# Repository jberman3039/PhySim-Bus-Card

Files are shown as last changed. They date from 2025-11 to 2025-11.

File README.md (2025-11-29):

# Physics-Simulating-Business-Card
 
The "Physics Simulating Business Card" is a electronic business card that runs on an STM32L412K8. The card contains an 8X8 LED matrix. The pixels in the matrix are individually addressable with a 74HC595 shift register controlling selecting rows and T2N7002 N-Channel MOSFETs controlling the columns. An MXC6655XA accelerometer is used to track orientation of the card which is used as input to a fluid simulation displayed on the LED matrix. This project is inspired by https://github.com/Nicholas-L-Johnson/flip-card.

Schematic
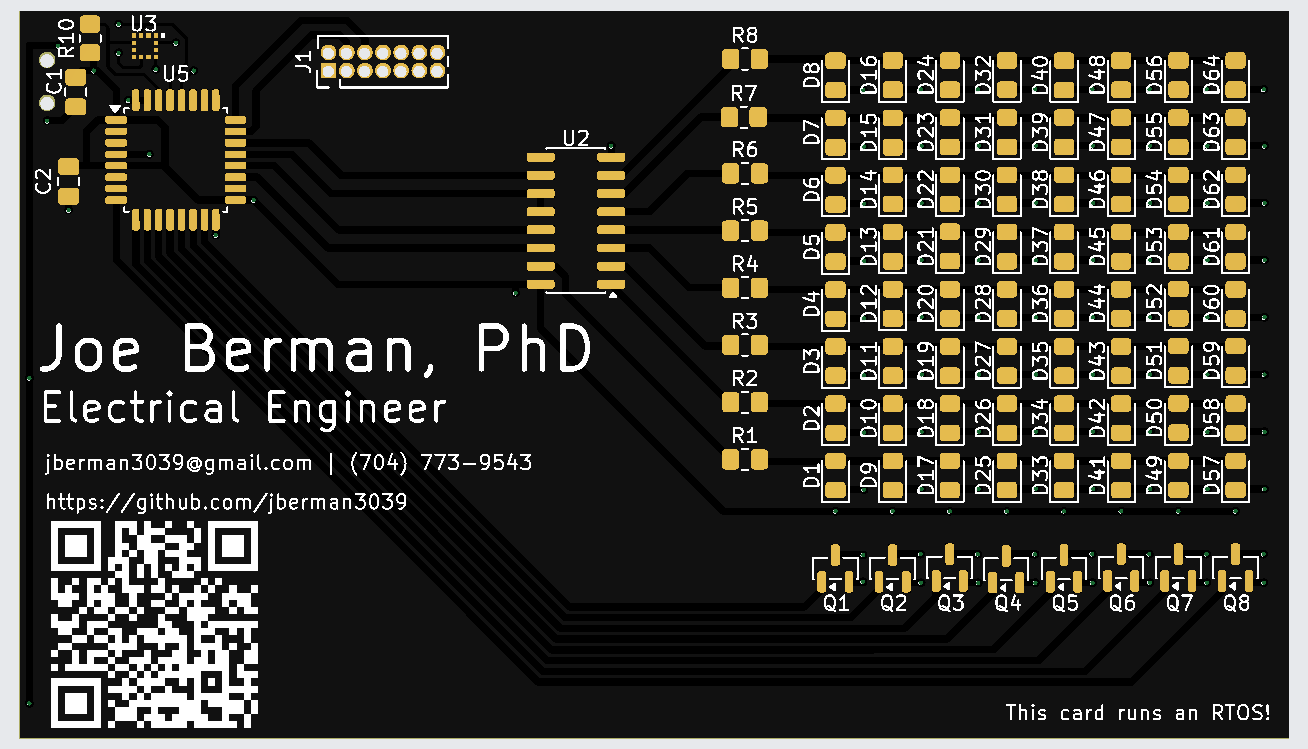
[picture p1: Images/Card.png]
PCB Design


# TODO

The firmware is currently in development. The STM32L412K8 will run CMSIS-RTOS for multi-threading tasks and will feature a custom driver for the MXC6655XA accelerometer.

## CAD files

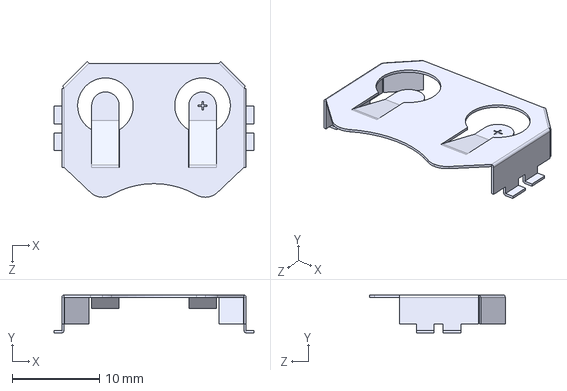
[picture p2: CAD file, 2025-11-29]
KiCad/BAT-HLD-001/BAT-HLD-001.step
22.9 x 4.32 x 15.5 mm

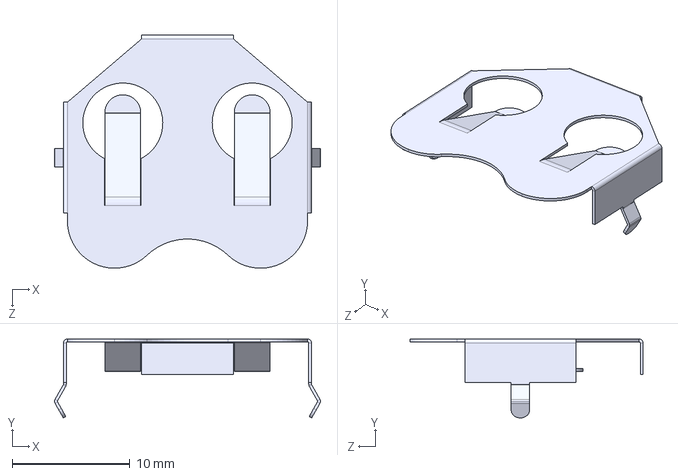
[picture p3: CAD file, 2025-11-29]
KiCad/BK_888_TR/BK-888.step
22.6 x 6.71 x 19.8 mm

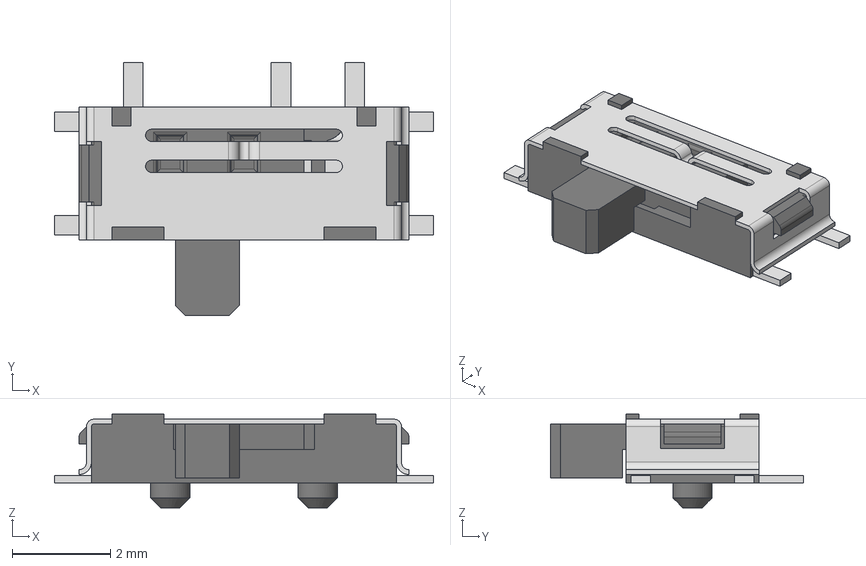
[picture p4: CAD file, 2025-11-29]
KiCad/450404015514/450404015514.step
7.70 x 5.13 x 1.90 mm
Frame
Pin 4
Frame 1
Pin 1
Pin 2
Pin 3
Slider 1
Slider
Cover

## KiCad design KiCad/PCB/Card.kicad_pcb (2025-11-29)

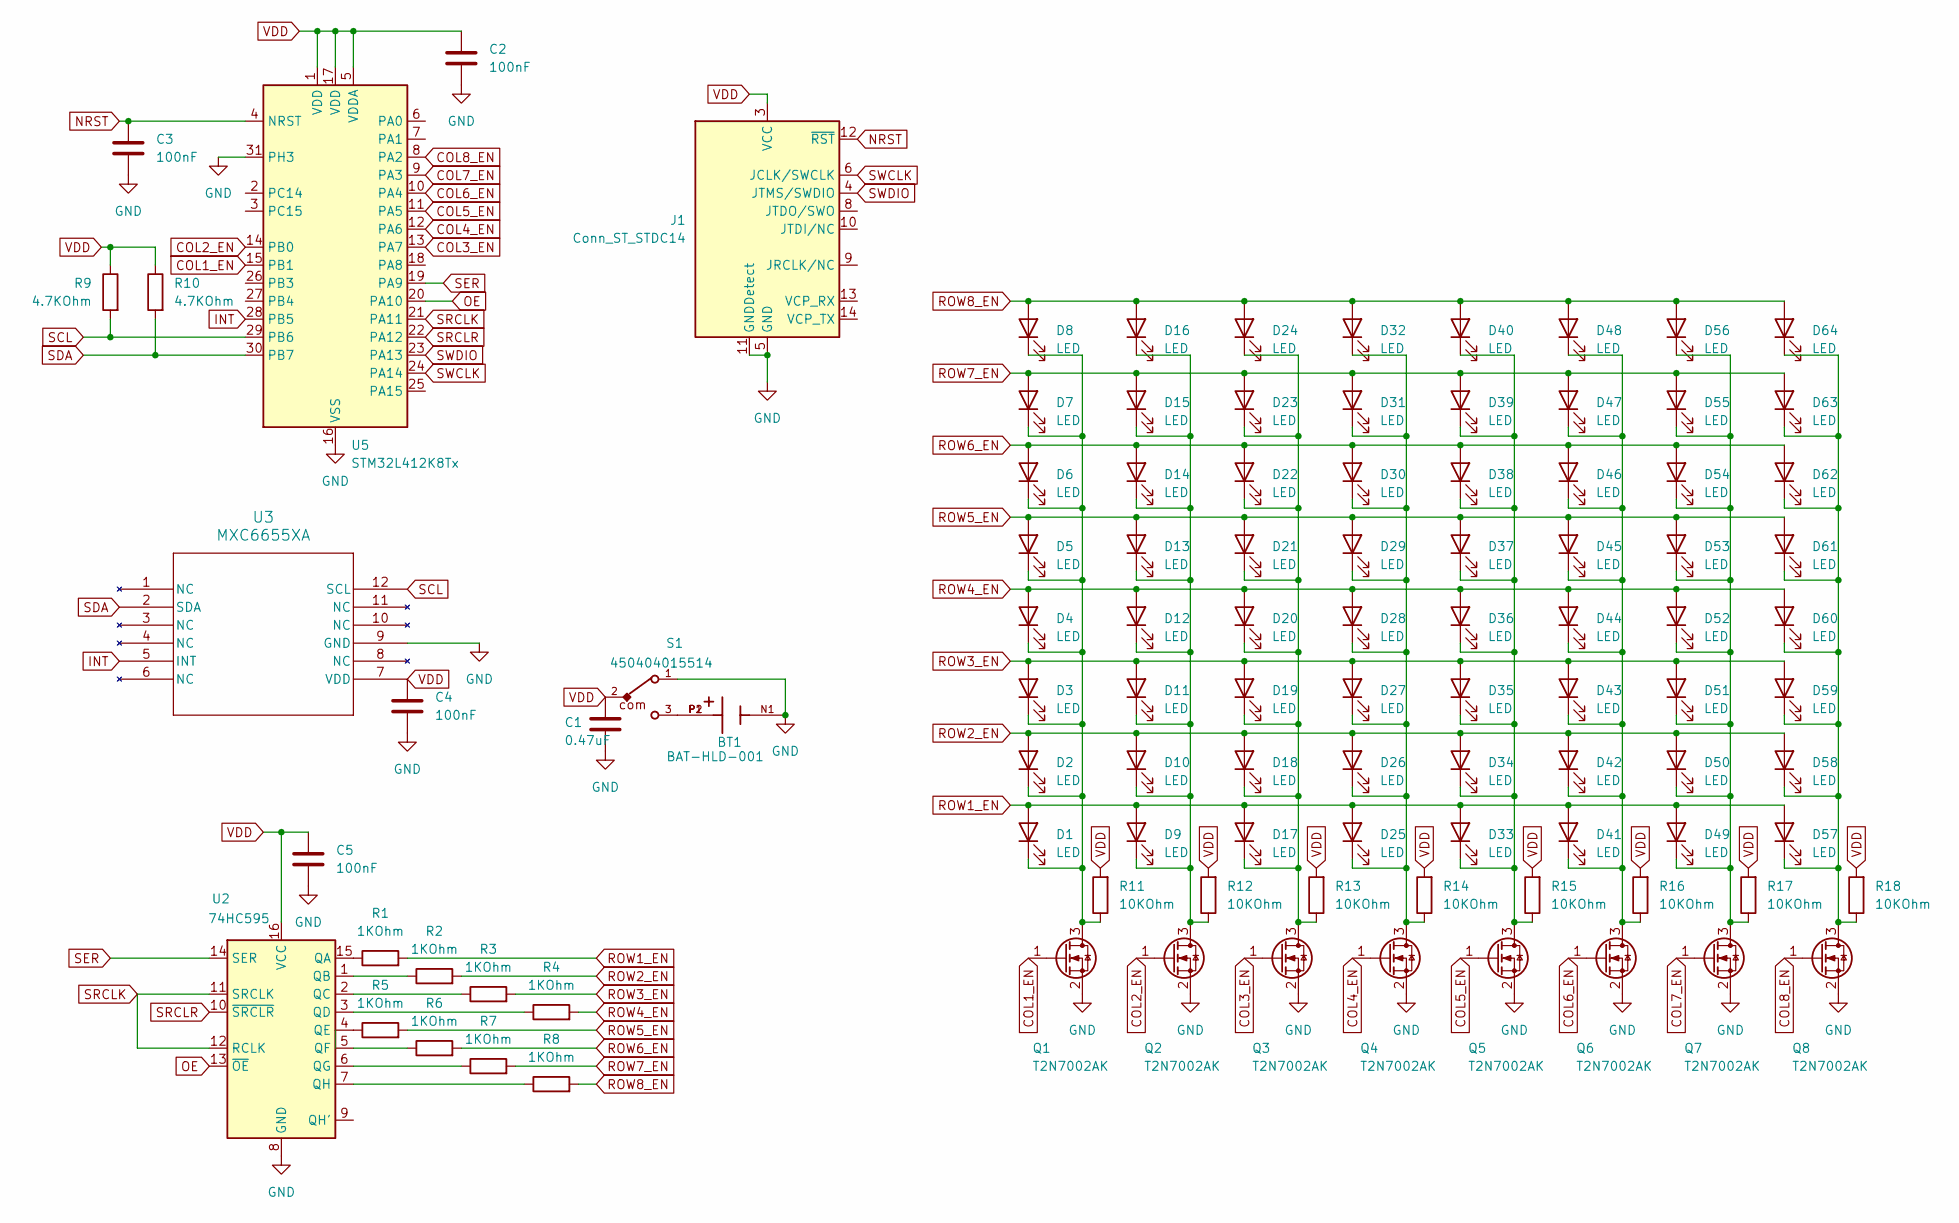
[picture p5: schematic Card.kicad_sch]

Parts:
BT1: BAT-HLD-001; BAT_BAT-HLD-001; PARTREV C
C1: 0.47uF; C_0805_2012Metric_Pad1.18x1.45mm_HandSolder
C2, C3, C4, C5: 100nF; C_0805_2012Metric_Pad1.18x1.45mm_HandSolder
D1, D2, D3, D4, D5, D6, D7, D8, D9, D10, D11, D12, D13, D14, D15, D16, D17, D18, D19, D20, D21, D22, D23, D24, D25, D26, D27, D28, D29, D30, D31, D32, D33, D34, D35, D36, D37, D38, D39, D40, D41, D42, D43, D44, D45, D46, D47, D48, D49, D50, D51, D52, D53, D54, D55, D56, D57, D58, D59, D60, D61, D62, D63, D64: LED; LED_0805_2012Metric_Pad1.15x1.40mm_HandSolder
J1: Conn_ST_STDC14; PinHeader_2x07_P1.27mm_Vertical
Q1, Q2, Q3, Q4, Q5, Q6, Q7, Q8: T2N7002AK; SOT-23
R1, R2, R3, R4, R5, R6, R7, R8: 1KOhm; R_0805_2012Metric_Pad1.20x1.40mm_HandSolder
R9, R10: 4.7KOhm; R_0805_2012Metric_Pad1.20x1.40mm_HandSolder
R11, R12, R13, R14, R15, R16, R17, R18: 10KOhm; R_0805_2012Metric_Pad1.20x1.40mm_HandSolder
S1: 450404015514
U2: 74HC595; SOIC-16_3.9x9.9mm_P1.27mm
U3: MXC6655XA; MXC6655XA_MEM
U5: STM32L412K8Tx; LQFP-32_7x7mm_P0.8mm

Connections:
COL1_EN: Q1.1 (G), U5.15 (PB1)
COL2_EN: Q2.1 (G), U5.14 (PB0)
COL3_EN: Q3.1 (G), U5.13 (PA7)
COL4_EN: Q4.1 (G), U5.12 (PA6)
COL5_EN: Q5.1 (G), U5.11 (PA5)
COL6_EN: Q6.1 (G), U5.10 (PA4)
COL7_EN: Q7.1 (G), U5.9 (PA3)
COL8_EN: Q8.1 (G), U5.8 (PA2)
GND: BT1.N1, C1.2, C2.2, C3.2, C4.2, C5.2, J1.5 (GND), J1.7 (GND), J1.11 (GNDDetect), Q1.2 (S), Q2.2 (S), Q3.2 (S), Q4.2 (S), Q5.2 (S), Q6.2 (S), Q7.2 (S), Q8.2 (S), S1.1, U2.8 (GND), U3.9 (GND), U5.16 (VSS), U5.31 (PH3), U5.32 (VSS)
INT: U3.5 (INT), U5.28 (PB5)
NRST: C3.1, J1.12 (~RST), U5.4 (NRST)
unnamed: BT1.P1, BT1.P2, S1.3
unnamed: D1.1 (K), D2.1 (K), D3.1 (K), D4.1 (K), D5.1 (K), D6.1 (K), D7.1 (K), D8.1 (K), Q1.3 (D), R11.1
unnamed: D9.1 (K), D10.1 (K), D11.1 (K), D12.1 (K), D13.1 (K), D14.1 (K), D15.1 (K), D16.1 (K), Q2.3 (D), R12.1
unnamed: D17.1 (K), D18.1 (K), D19.1 (K), D20.1 (K), D21.1 (K), D22.1 (K), D23.1 (K), D24.1 (K), Q3.3 (D), R13.1
unnamed: D25.1 (K), D26.1 (K), D27.1 (K), D28.1 (K), D29.1 (K), D30.1 (K), D31.1 (K), D32.1 (K), Q4.3 (D), R14.1
unnamed: D33.1 (K), D34.1 (K), D35.1 (K), D36.1 (K), D37.1 (K), D38.1 (K), D39.1 (K), D40.1 (K), Q5.3 (D), R15.1
unnamed: D41.1 (K), D42.1 (K), D43.1 (K), D44.1 (K), D45.1 (K), D46.1 (K), D47.1 (K), D48.1 (K), Q6.3 (D), R16.1
unnamed: D49.1 (K), D50.1 (K), D51.1 (K), D52.1 (K), D53.1 (K), D54.1 (K), D55.1 (K), D56.1 (K), Q7.3 (D), R17.1
unnamed: D57.1 (K), D58.1 (K), D59.1 (K), D60.1 (K), D61.1 (K), D62.1 (K), D63.1 (K), D64.1 (K), Q8.3 (D), R18.1
unnamed: R1.1, U2.15 (QA)
unnamed: R2.1, U2.1 (QB)
unnamed: R3.1, U2.2 (QC)
unnamed: R4.1, U2.3 (QD)
unnamed: R5.1, U2.4 (QE)
unnamed: R6.1, U2.5 (QF)
unnamed: R7.1, U2.6 (QG)
unnamed: R8.1, U2.7 (QH)
OE: U2.13 (~OE), U5.20 (PA10)
ROW1_EN: D1.2 (A), D9.2 (A), D17.2 (A), D25.2 (A), D33.2 (A), D41.2 (A), D49.2 (A), D57.2 (A), R1.2
ROW2_EN: D2.2 (A), D10.2 (A), D18.2 (A), D26.2 (A), D34.2 (A), D42.2 (A), D50.2 (A), D58.2 (A), R2.2
ROW3_EN: D3.2 (A), D11.2 (A), D19.2 (A), D27.2 (A), D35.2 (A), D43.2 (A), D51.2 (A), D59.2 (A), R3.2
ROW4_EN: D4.2 (A), D12.2 (A), D20.2 (A), D28.2 (A), D36.2 (A), D44.2 (A), D52.2 (A), D60.2 (A), R4.2
ROW5_EN: D5.2 (A), D13.2 (A), D21.2 (A), D29.2 (A), D37.2 (A), D45.2 (A), D53.2 (A), D61.2 (A), R5.2
ROW6_EN: D6.2 (A), D14.2 (A), D22.2 (A), D30.2 (A), D38.2 (A), D46.2 (A), D54.2 (A), D62.2 (A), R6.2
ROW7_EN: D7.2 (A), D15.2 (A), D23.2 (A), D31.2 (A), D39.2 (A), D47.2 (A), D55.2 (A), D63.2 (A), R7.2
ROW8_EN: D8.2 (A), D16.2 (A), D24.2 (A), D32.2 (A), D40.2 (A), D48.2 (A), D56.2 (A), D64.2 (A), R8.2
SCL: R9.2, U3.12 (SCL), U5.29 (PB6)
SDA: R10.2, U3.2 (SDA), U5.30 (PB7)
SER: U2.14 (SER), U5.19 (PA9)
SRCLK: U2.11 (SRCLK), U2.12 (RCLK), U5.21 (PA11)
SRCLR: U2.10 (~SRCLR), U5.22 (PA12)
SWCLK: J1.6 (JCLK/SWCLK), U5.24 (PA14)
SWDIO: J1.4 (JTMS/SWDIO), U5.23 (PA13)
VDD: C1.1, C2.1, C4.1, C5.1, J1.3 (VCC), R9.1, R10.1, R11.2, R12.2, R13.2, R14.2, R15.2, R16.2, R17.2, R18.2, S1.2, U2.16 (VCC), U3.7 (VDD), U5.1 (VDD), U5.5 (VDDA), U5.17 (VDD)

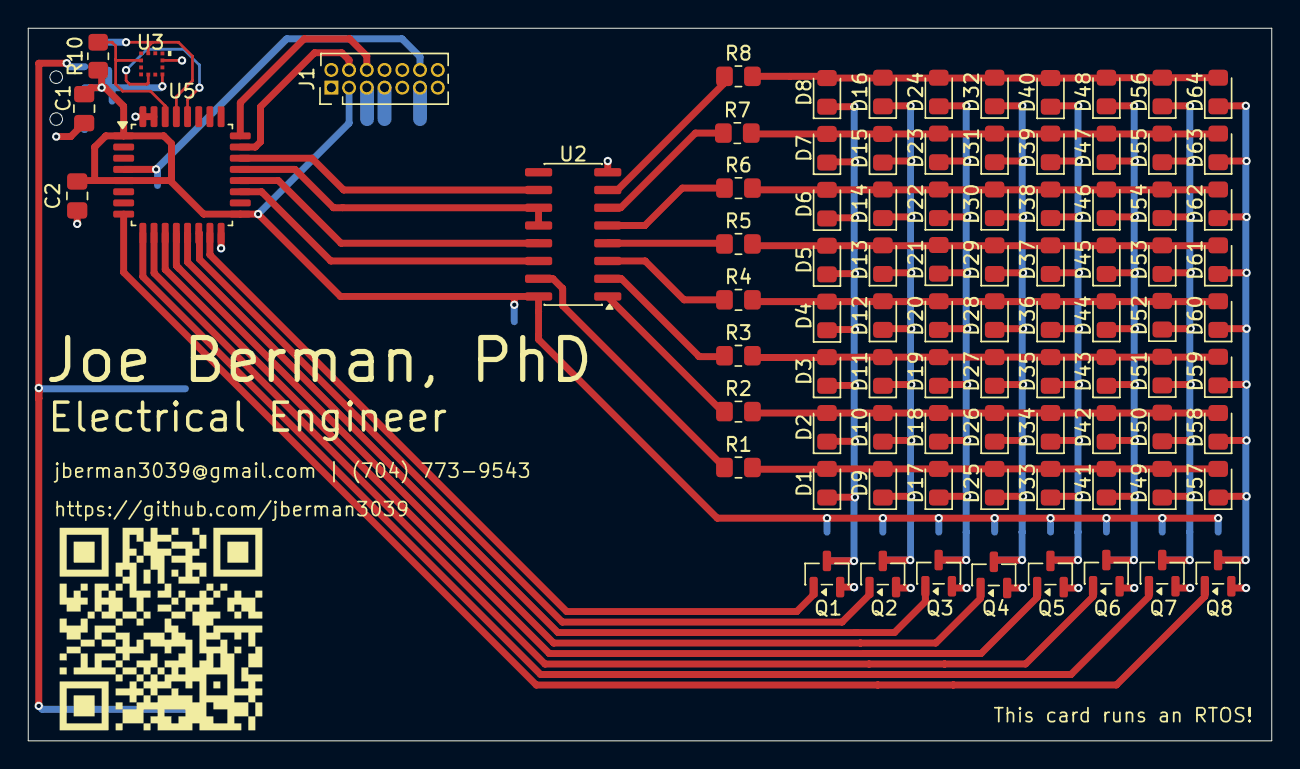
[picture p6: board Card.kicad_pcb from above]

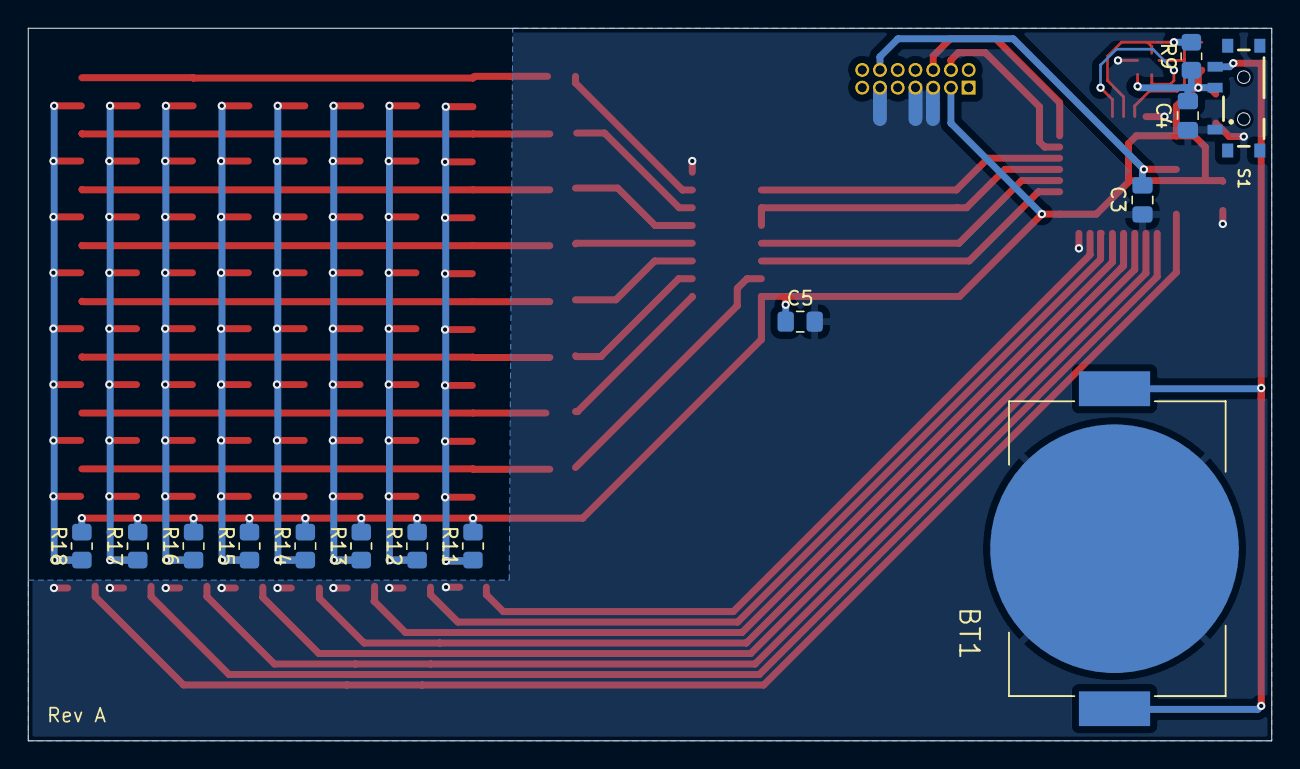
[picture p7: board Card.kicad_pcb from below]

Board: 2 copper layers, 89.0 x 51.0 mm, 102 parts (14 on the bottom side), 45 nets.

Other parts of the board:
QR*****: Github_QR
